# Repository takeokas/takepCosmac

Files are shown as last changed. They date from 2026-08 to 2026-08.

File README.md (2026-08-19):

# takepCosmac
COSMAC CDP1802 Single Board Computer,  1802 MemberChip Card互換

<a href="https://sunrise-ev.com/photos/1802/1802me2-manual.pdf" target=_blank> 1802 MemberChip Card </a> 互換  
<a href="https://hackaday.io/project/190289-1802-memberchip-card" target=_blank> 1802 MemberChip Card in Hackaday.io </a>  

<a href="https://cdn.hackaday.io/files/1902898141324576/MC21ANSA.bin"> MC21ANSA.bin </a> を、ROMの先頭(0番地)から書き込むと動作する  

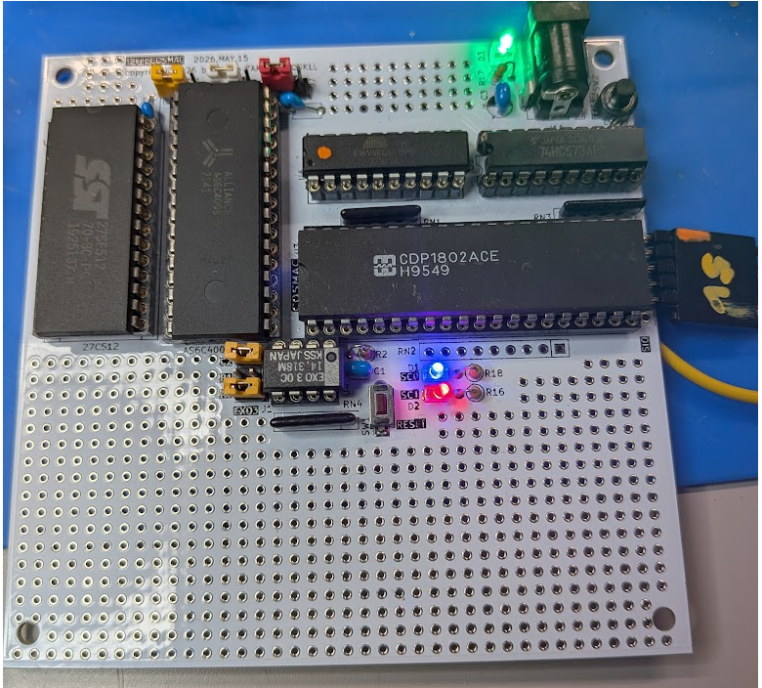
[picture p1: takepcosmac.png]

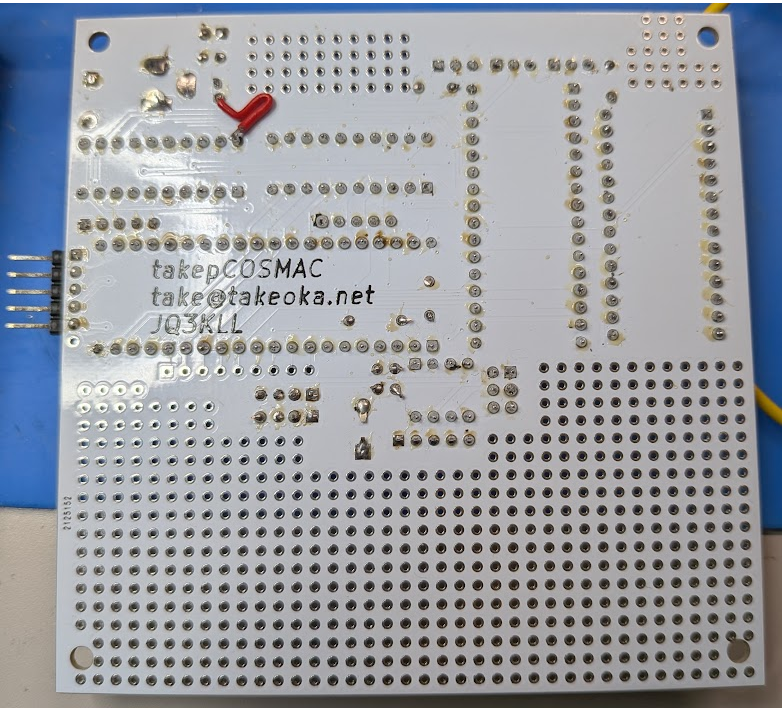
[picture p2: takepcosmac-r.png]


**※74HC573 の電源に +5V を接続すること!!(重要)**  

## Spec  
- RAMは、メモリ空間の後半 32KBytes  
-- S-RAM,  AS6C4008-55PCN (512KW×8bit)1チップ使用  

- ROMは、メモリ空間の前半 32K  
-- EEPROM,  SST 27SF512(64KW×8bit)) 使用  
-- 27C512互換であれば使用可能、2764あたりからそのまま差し込めるはず  
-- ROMの通常アクセスは、前半 32KBytes (0〜0x7FFF)であるが…  
-- ROMの後半 32KBytes (0x8000〜0xFFFF)は、RAMとかぶっているが、IO readアクセスで読み出し可能  
--- ROMの後半を読み出して、RAMに転送することができる!  

- Crystal発振器 EPSON EXO-3, 14.31818 MHz の8分周  
-- CPU は、約 1.7898 MHz で動作  

- GAL16V8 使用  
-- <a href="takepCosmacGal/takepCosmac.pld"> 論理(ソース) </a>  
-- <a href="takepCosmacGal/takepCosmac.jed"> JDECファイル </a>  

- SIO TTLレベル  
-- ソフトウェア実現.4800bps が調子いい  
-- 秋月で販売されている FTDI USBシリアル変換ケーブル(5V) が直接 差せる  
--  https://akizukidenshi.com/catalog/g/g105841/    

## 超簡略 使用方法 説明  
- シリアル・ラインに端末を接続する。ソフトウェアでSIO処理を行っているので、4800bpsが限界ぽい  
- COSMACをリセットする。リセット後、何も出力されない。シリアル端末で「リターン」を押下(\r を送信)
- MC21ANSA が自動で、通信速度を判定。起動メッセージを出力
- 入力する英文字は、大文字のみ  
- 「H」(大文字)で、help が出力される。
- 「P」でアドベンチャーゲーム。詳しくは<a href="https://sunrise-ev.com/photos/1802/1802me2-manual.pdf" target=_blank> 1802 MemberChip Card マニュアルPDF</a> の P.15  
- 「B」で BASIC インタープリタ。  
  -- 起動直後に「Cold start」か尋ねられるので、「C」でコールド・スタート  
  -- 「PR」 で「PRINT」の省略形。他は、一般的な BASIC と同様  
  -- <a href="https://sunrise-ev.com/MembershipCard/BASIC3v11user.pdf"> BASIC のマニュアル </a>  

## 1802 MemberChip Card の特殊なROMチップ・セレクトについて  
- <a href="https://sunrise-ev.com/photos/1802/1802me2-manual.pdf" target=_blank> 1802 MemberChip Card マニュアルPDF</a> の「Banked Memory」の章(P.21)に説明がある  
- <a href="https://hackaday.io/project/190289-1802-memberchip-card" target=_blank> 1802 MemberChip Card in Hackaday.io </a> にも解説がある  

  

- PROMの上位 32KBytes (0x8000〜0xFFFF) を読む方法  
  1.  読み出したいアドレスをレジスタにセットする。ただし、MSBは0にすること。例えば0x9000 を読みたいならば 0x1000 とする  
  2.  Xに、このレジスタの値をセットする。SEX命令などで  
  3.  「INP 0」(オペコード 0x68) 命令を実行する。通常、これは未定義命令である。  
     この命令は、入力ポート(N0-N2線)の指定無しで、読み込みをおこなう  
     CPU は、write サイクルを実行するが、PROMの後半から read し、CPU の Dレジスタに読み込む  
- MC21ANSA モニタの「E」コマンドは、PROMの後半から RAM へのブロック転送を行う  
  - 「E ソース番地 目的番地 バイト数」で、各パラメータは十六進数で指定  
       ソース番地:PROMアドレス、目的番地:RAMアドレス  

### 1802 MemberChip Card の特殊なROMチップ・セレクトの解説  
-- PROMの 下位 32KBを read するとき: A15=0 , /MRD=0 (通常).  
-- しかし、PROMの 下位 32KBに write するとき: A15=0, /MWR=0 , /MRD=1。  
--- /MWR=0 は PROM をチップ・セレクトし、CPUの A15=0 は PROM の read enable し、そして /MRD=1 は ROM address の A15ビットを Hi にする。  
    それにより、PROM の上位(0x8000-0xFFFF)を読み出す。  
--- しかし CPU データ・バスの出力と、PROM の出力がぶつかるのは困る。よって、CPUの INP 命令を使用する。(INP命令はデータ・バスに何も出さない)      
--- 以上により、CPU の Dレジスタに PROM のデータが入る

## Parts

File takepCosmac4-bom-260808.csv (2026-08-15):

# | Reference | Qty | Value | Footprint | DNP
1 | C1 | 1 | 10uF | Capacitor_THT:C_Disc_D3.0mm_W2.0mm_P2.50mm
2 | C2, C4, C5 | 3 | 0.1uF | Capacitor_THT:C_Disc_D4.7mm_W2.5mm_P5.00mm
3 | C3 | 1 | 電解10uF | Capacitor_THT:CP_Radial_D4.0mm_P2.00mm
4 | D1, D2 | 2 | LED | LED_THT:LED_D1.8mm_W3.3mm_H2.4mm
5 | D3 | 1 | LED | LED_THT:LED_D3.0mm
6 | H1, H2, H3, H4 | 4 | MountingHole | MountingHole:MountingHole_3.2mm_M3
7 | J1 | 1 | HEADER_3x2 | Connector_PinHeader_2.54mm:PinHeader_2x03_P2.54mm_Vertical
8 | J3 | 1 | HEADER_3,RAM0a18 | Connector_PinHeader_2.54mm:PinHeader_1x03_P2.54mm_Vertical
9 | J5 | 1 | HEADER_6,SIOA | Connector_PinHeader_2.54mm:PinHeader_1x06_P2.54mm_Horizontal
10 | J6 | 1 | HEADER_3,RAM0a17 | Connector_PinHeader_2.54mm:PinHeader_1x03_P2.54mm_Vertical
11 | J7 | 1 | HEADER_3,RAM0a16 | Connector_PinHeader_2.54mm:PinHeader_1x03_P2.54mm_Vertical
12 | J11 | 1 | Barrel_Jack | Connector_BarrelJack:BarrelJack_GCT_DCJ200-10-A_Horizontal
13 | R1 | 1 | 10K | Resistor_THT:R_Axial_DIN0207_L6.3mm_D2.5mm_P7.62mm_Horizontal
14 | R2 | 1 | 10K | Resistor_THT:R_Axial_DIN0207_L6.3mm_D2.5mm_P2.54mm_Vertical
15 | R16, R18 | 2 | R,330 | Resistor_THT:R_Axial_DIN0207_L6.3mm_D2.5mm_P2.54mm_Vertical
16 | R17 | 1 | 330 | Resistor_THT:R_Axial_DIN0207_L6.3mm_D2.5mm_P2.54mm_Vertical
17 | RN1, RN4 | 2 | R_Network04,10K | Resistor_THT:R_Array_SIP5
18 | RN2 | 1 | R_Network_22K | Resistor_THT:R_Array_SIP9
19 | RN3 | 1 | R_Network04.10K | Resistor_THT:R_Array_SIP5
20 | SW1 | 1 | Reset | Button_Switch_THT:SW_PUSH_1P1T_6x3.5mm_H5.0_APEM_MJTP1250
21 | SW2 | 1 | EF4 | Button_Switch_THT:SW_PUSH_1P1T_6x3.5mm_H5.0_APEM_MJTP1250
22 | U1 | 1 | AS6C4008-55PCN | Package_DIP:DIP-32_W15.24mm
23 | U3 | 1 | CDP1802ACE | Package_DIP:DIP-40_W15.24mm_Socket
24 | U4 | 1 | EXO3 クリスタルオシレータ 14.31818MHz | Package_DIP:DIP-8_W7.62mm |  | https://akizukidenshi.com/catalog/g/g101685/
25 | U5 | 1 | 74LS573 | Package_DIP:DIP-20_W7.62mm
26 | U6 | 1 | GAL16V8D-10QPN | Package_DIP:DIP-20_W7.62mm_Socket
27 | U8 | 1 | 27C512 | Package_DIP:DIP-28_W15.24mm_Socket

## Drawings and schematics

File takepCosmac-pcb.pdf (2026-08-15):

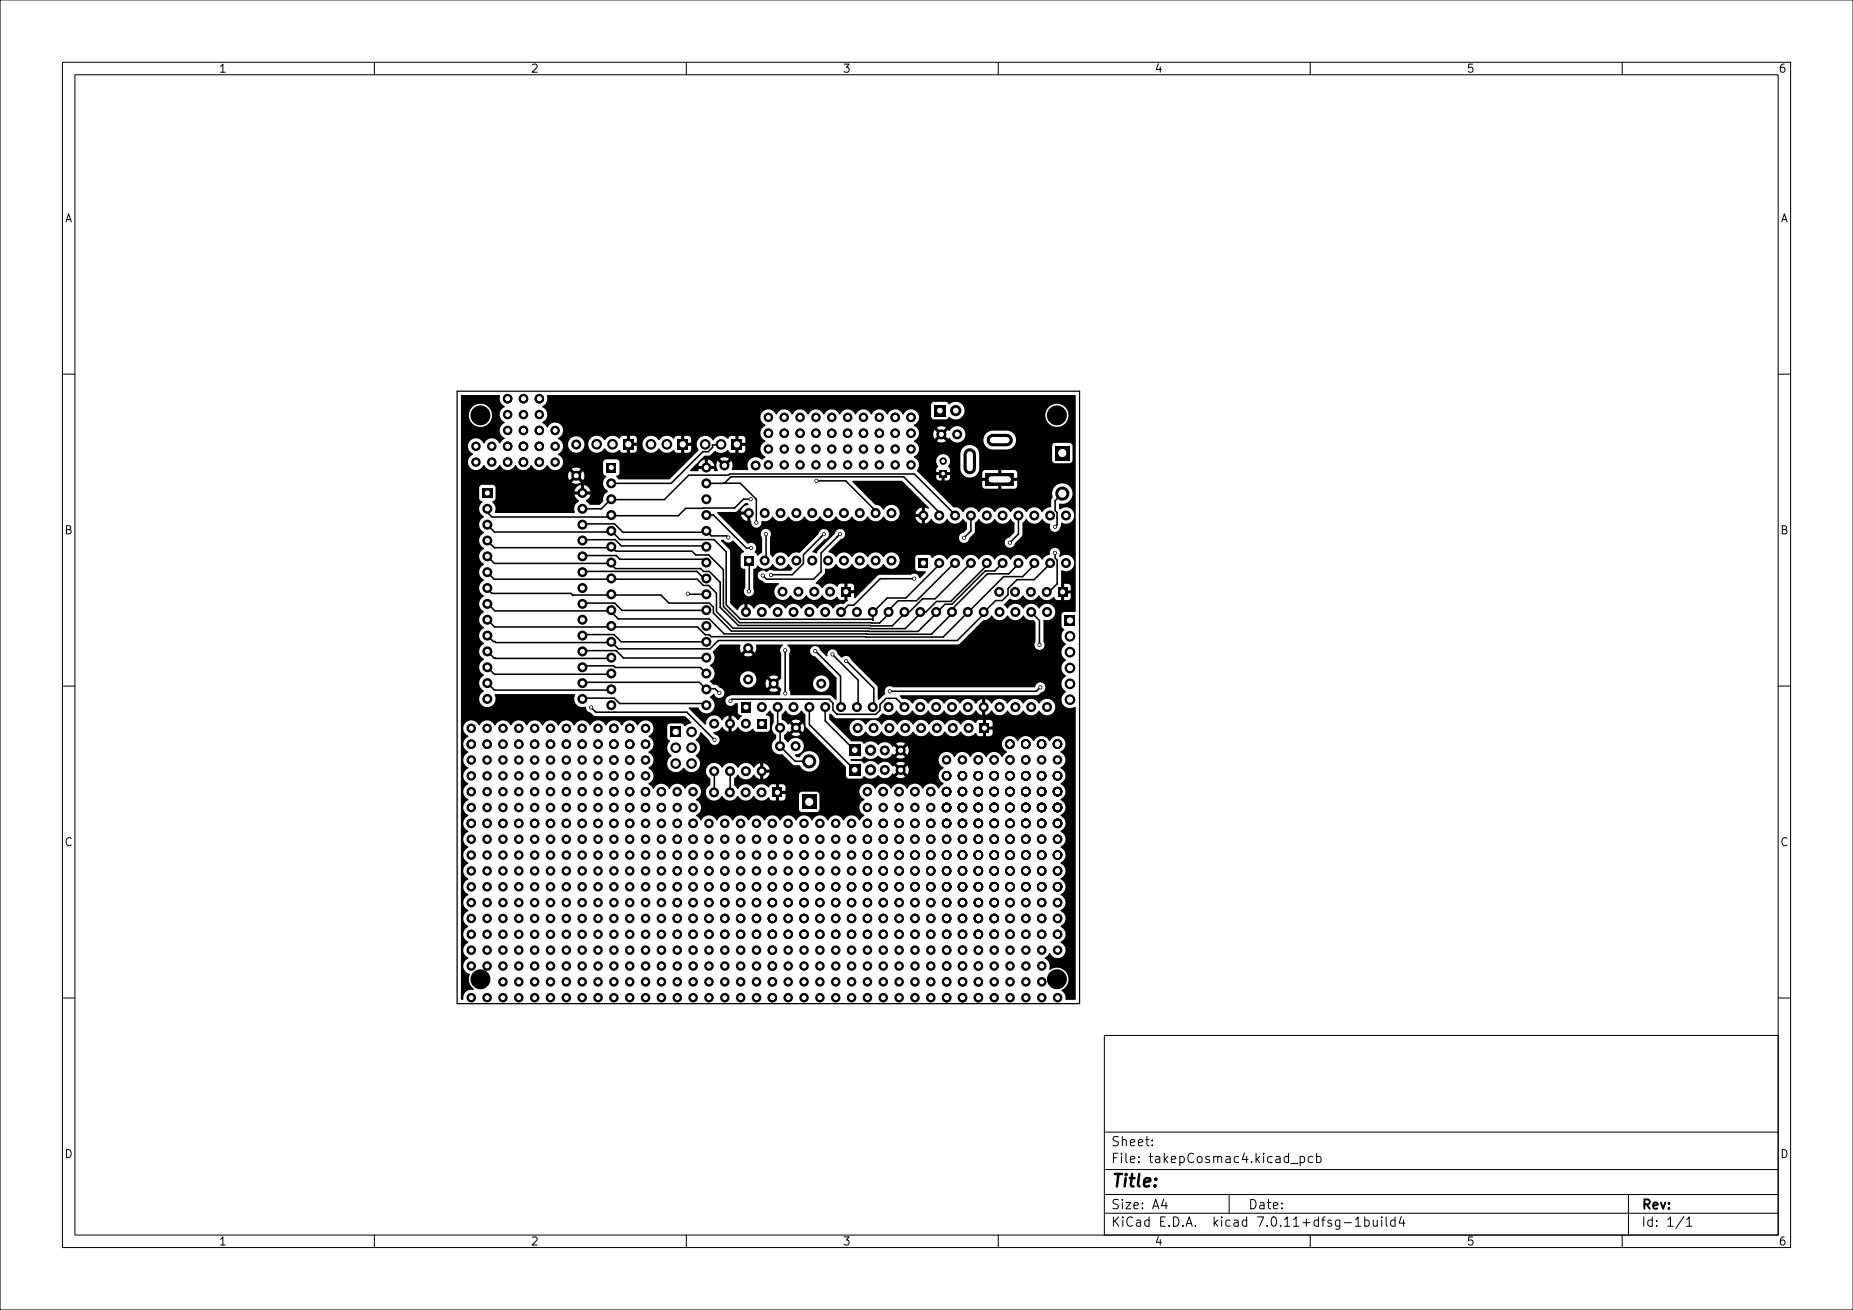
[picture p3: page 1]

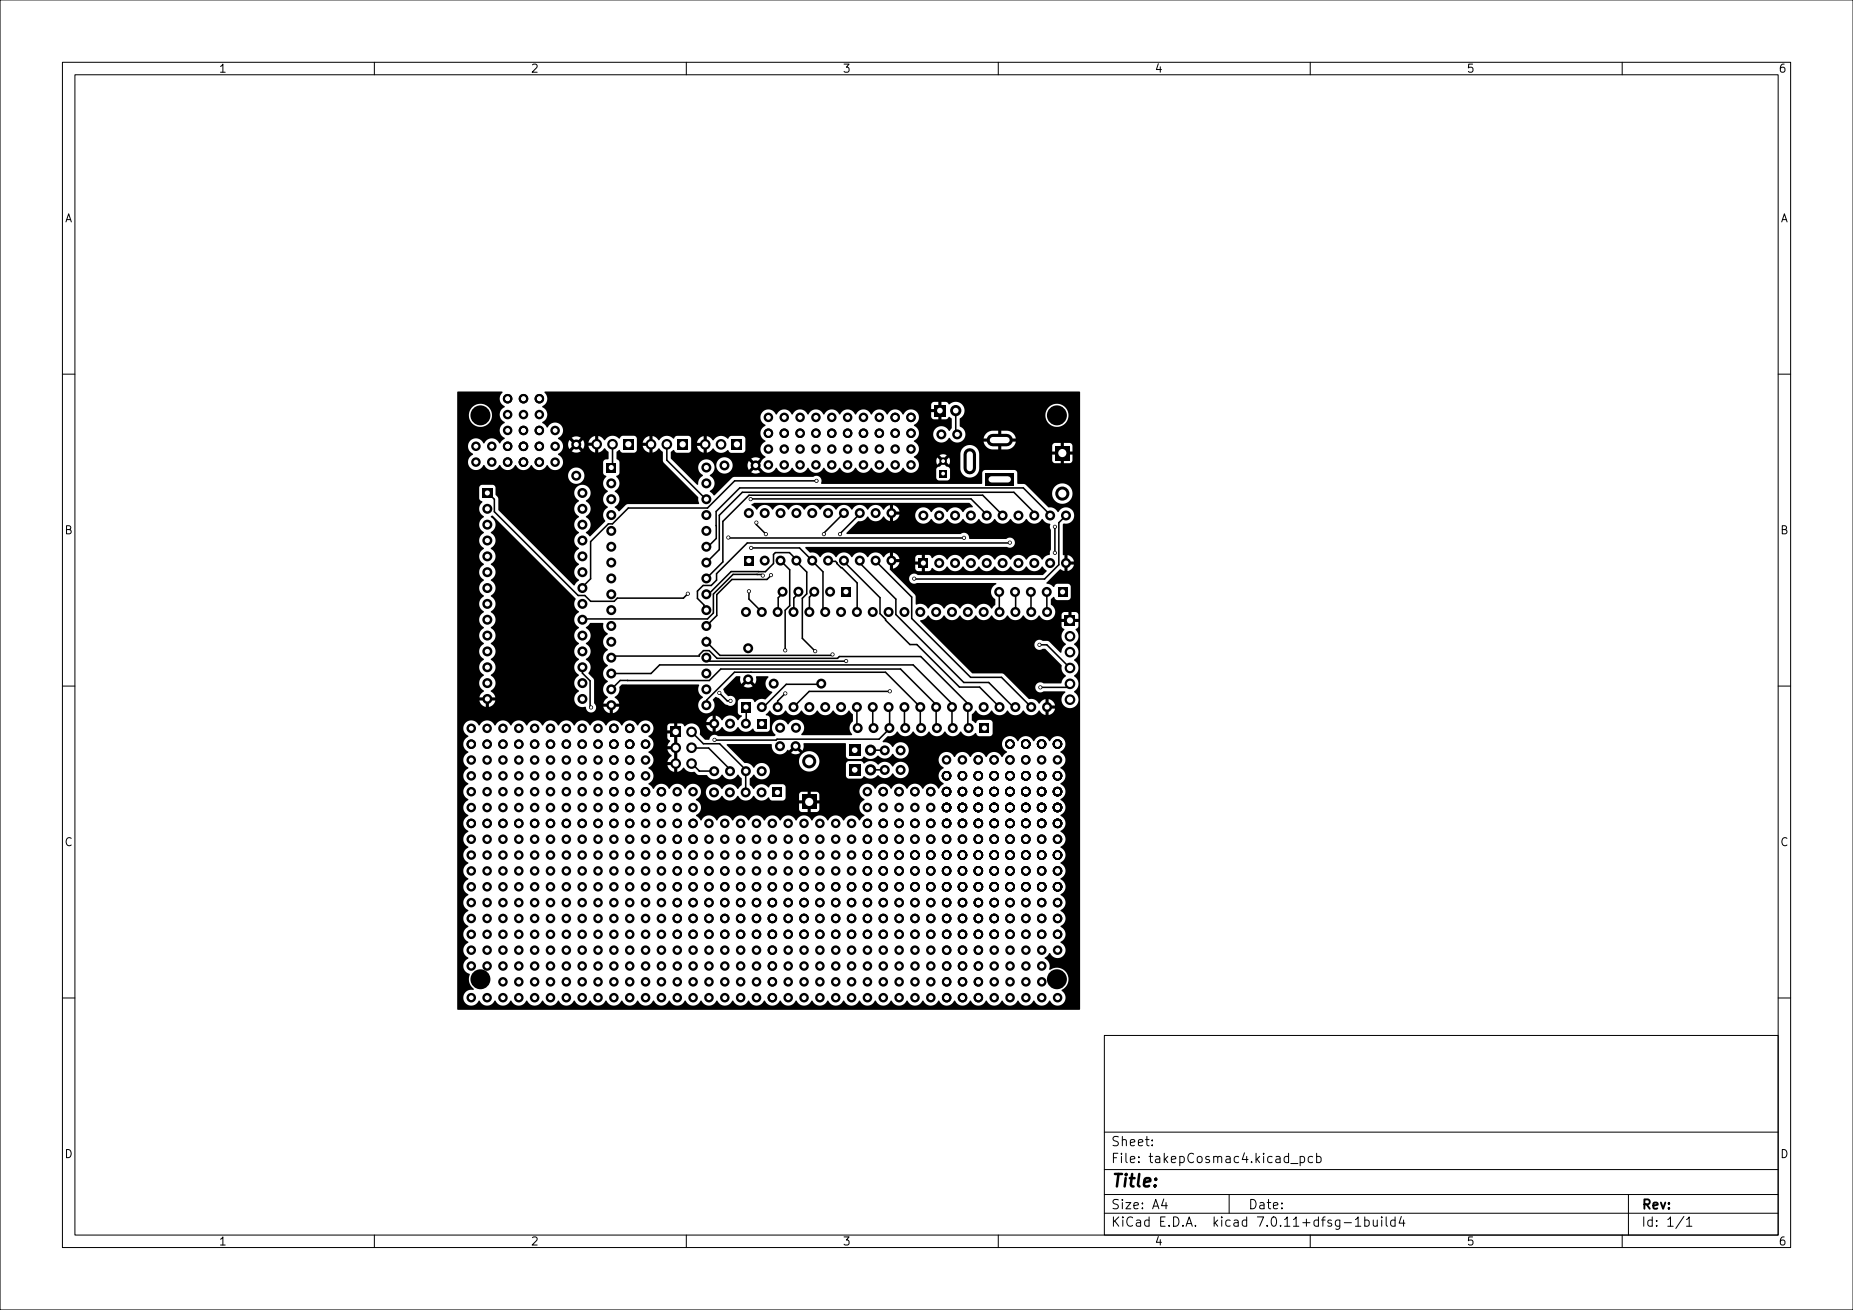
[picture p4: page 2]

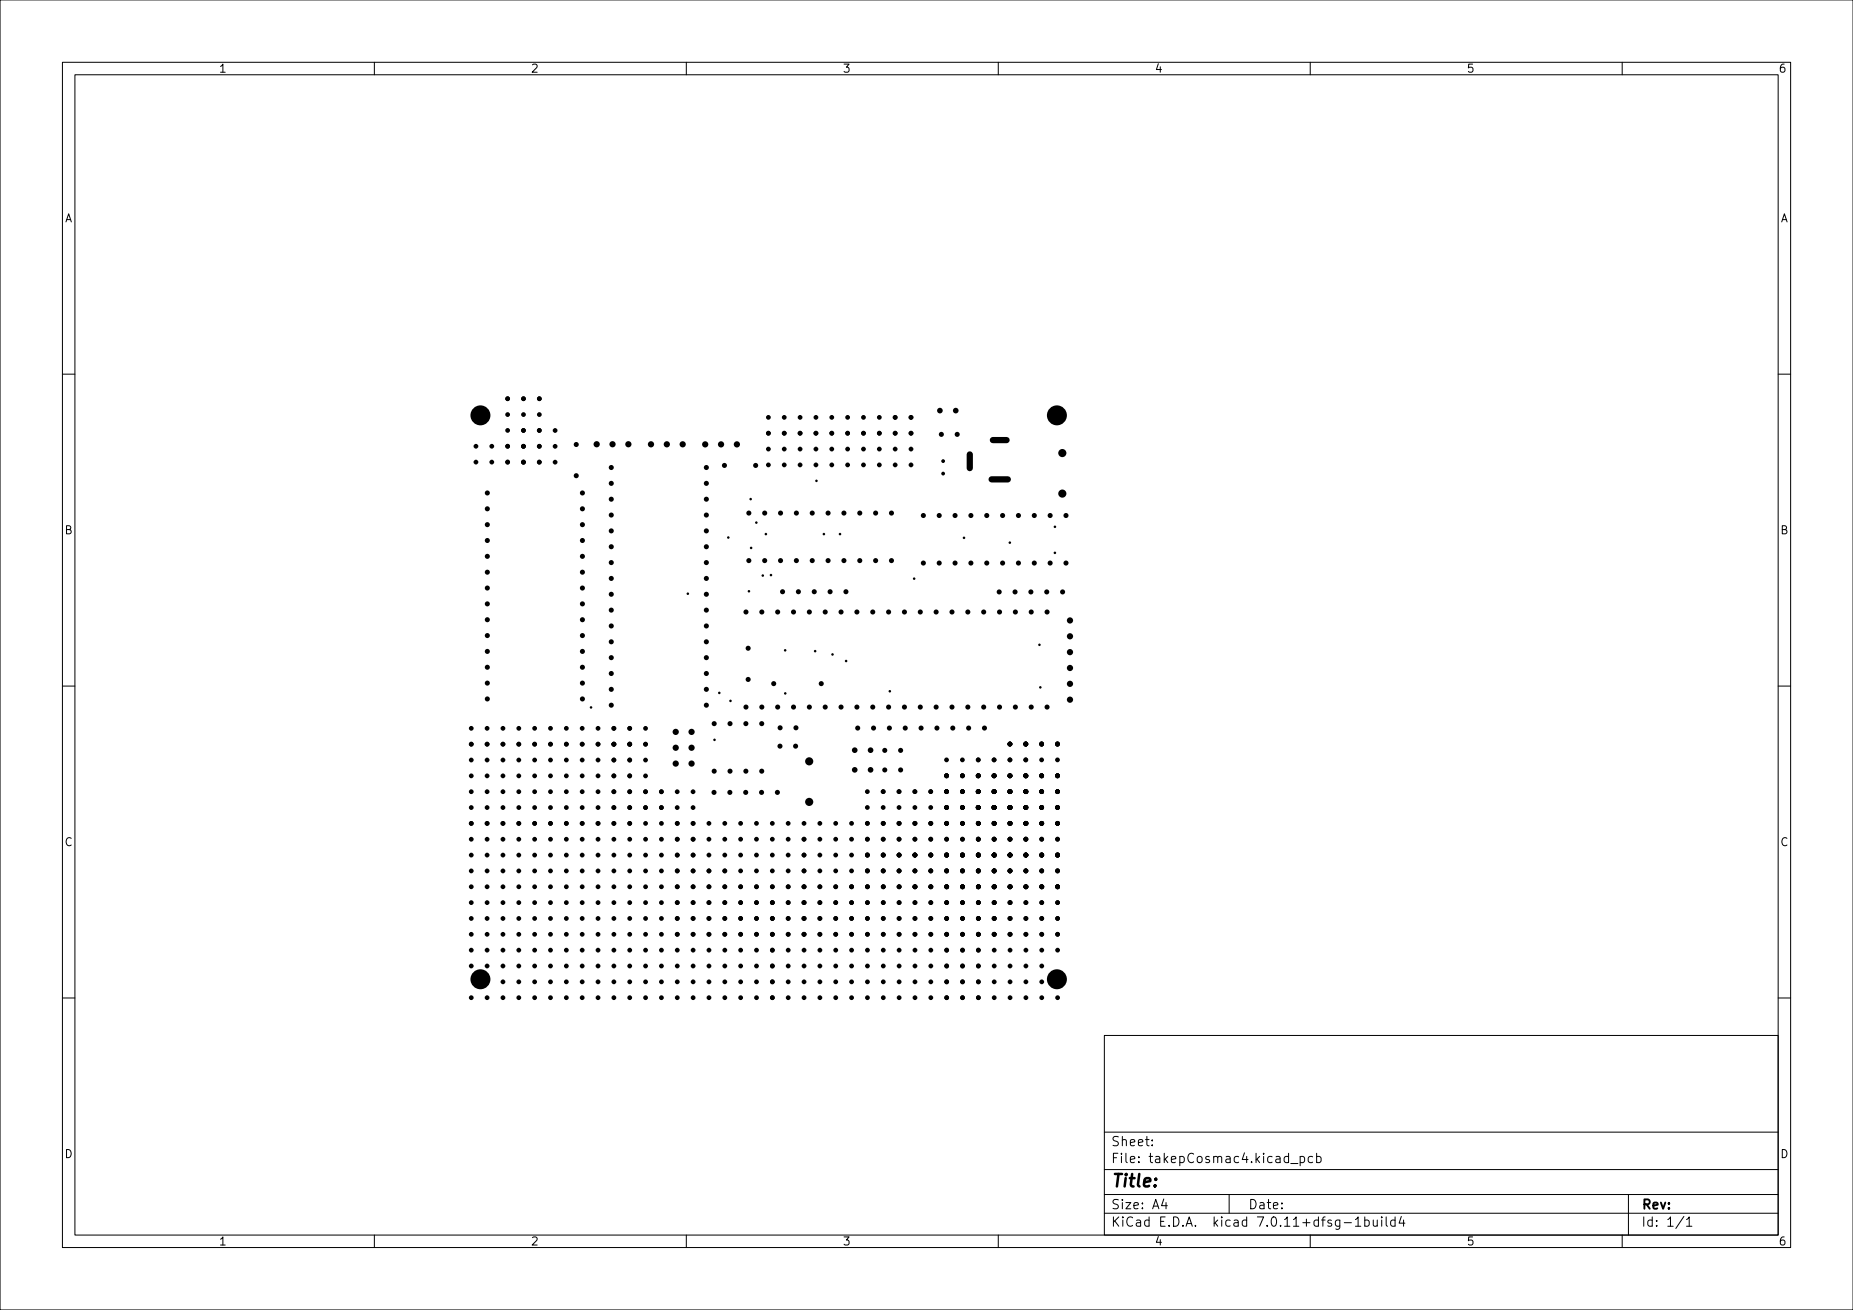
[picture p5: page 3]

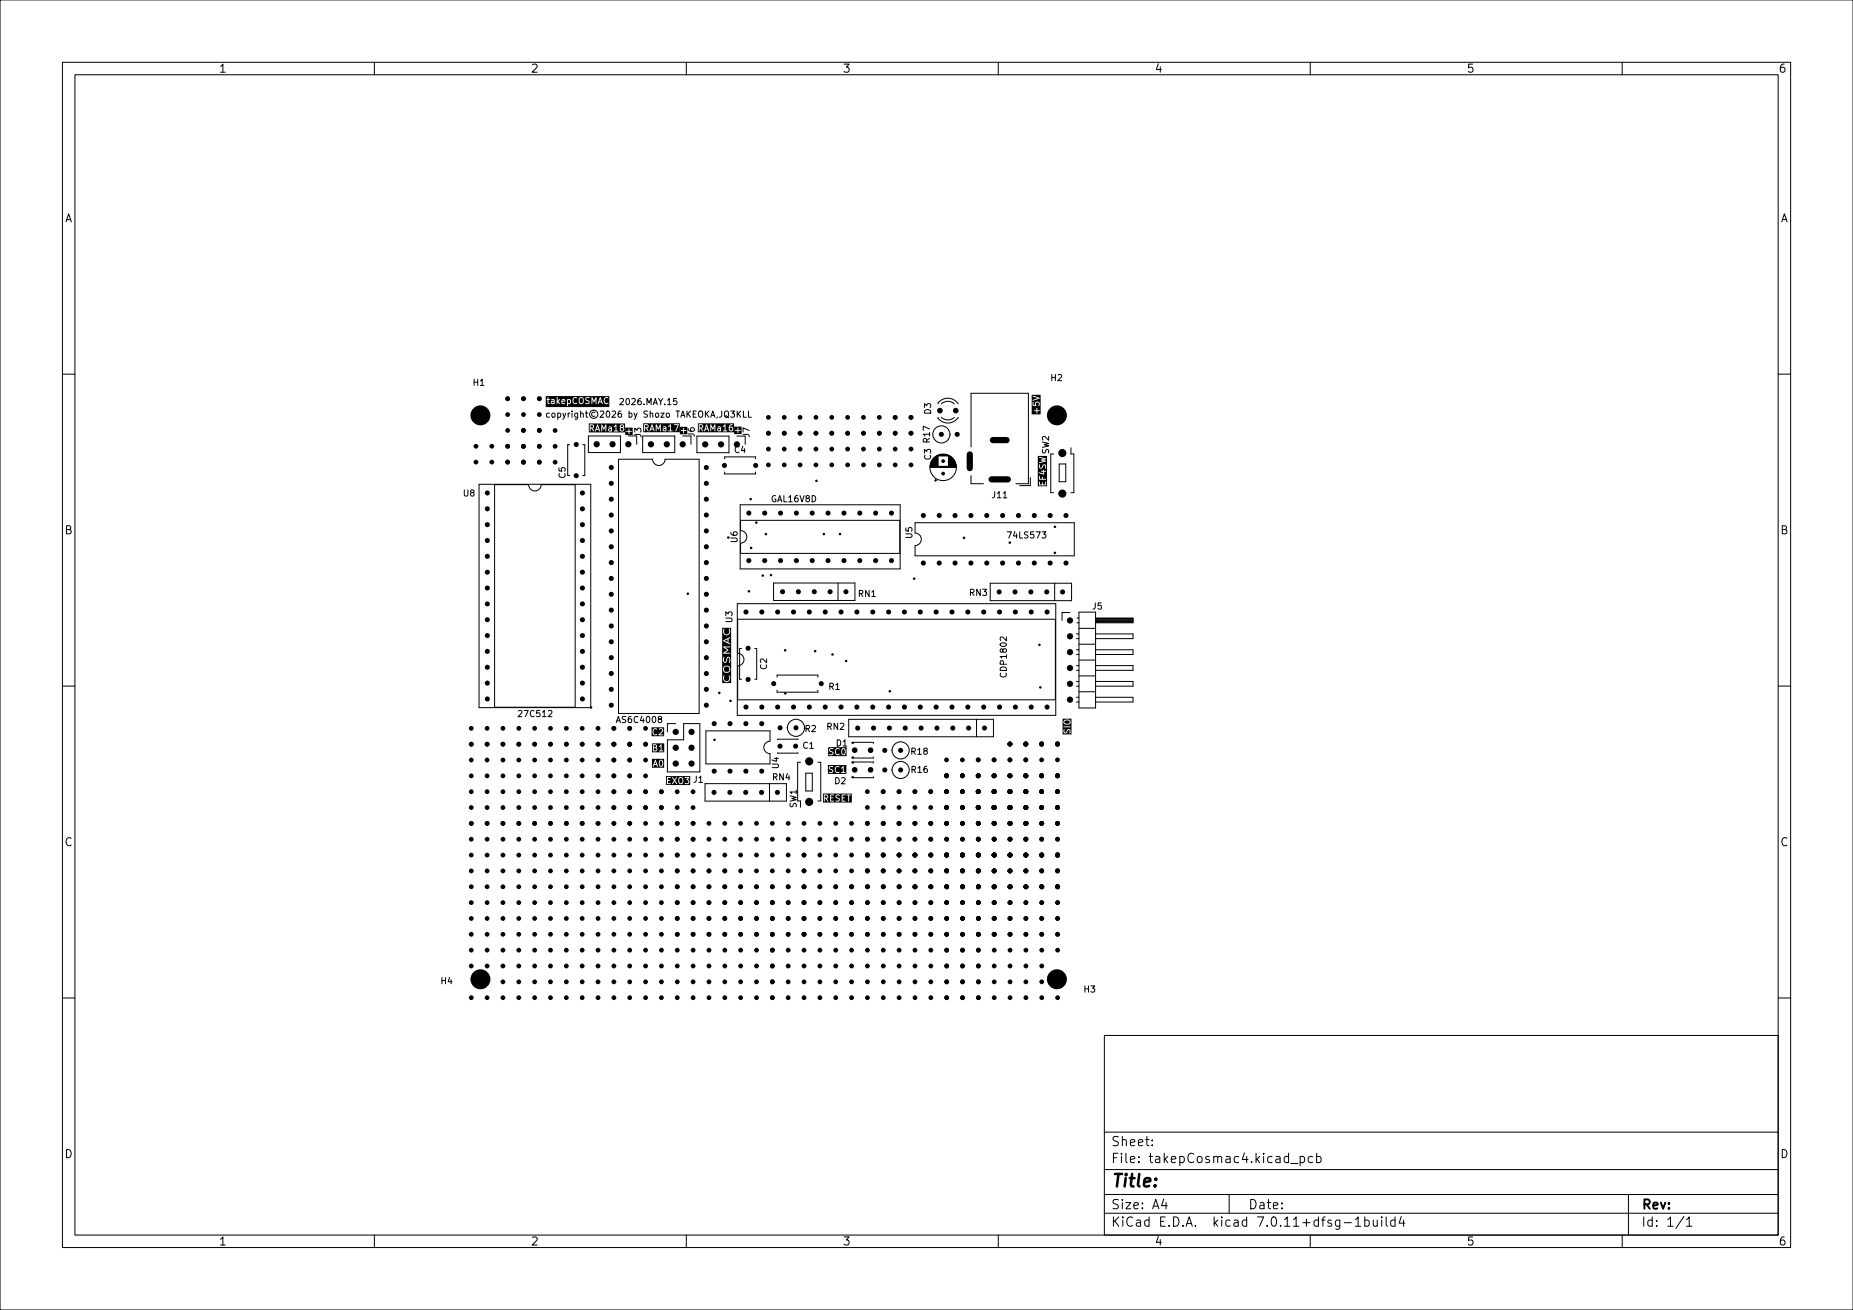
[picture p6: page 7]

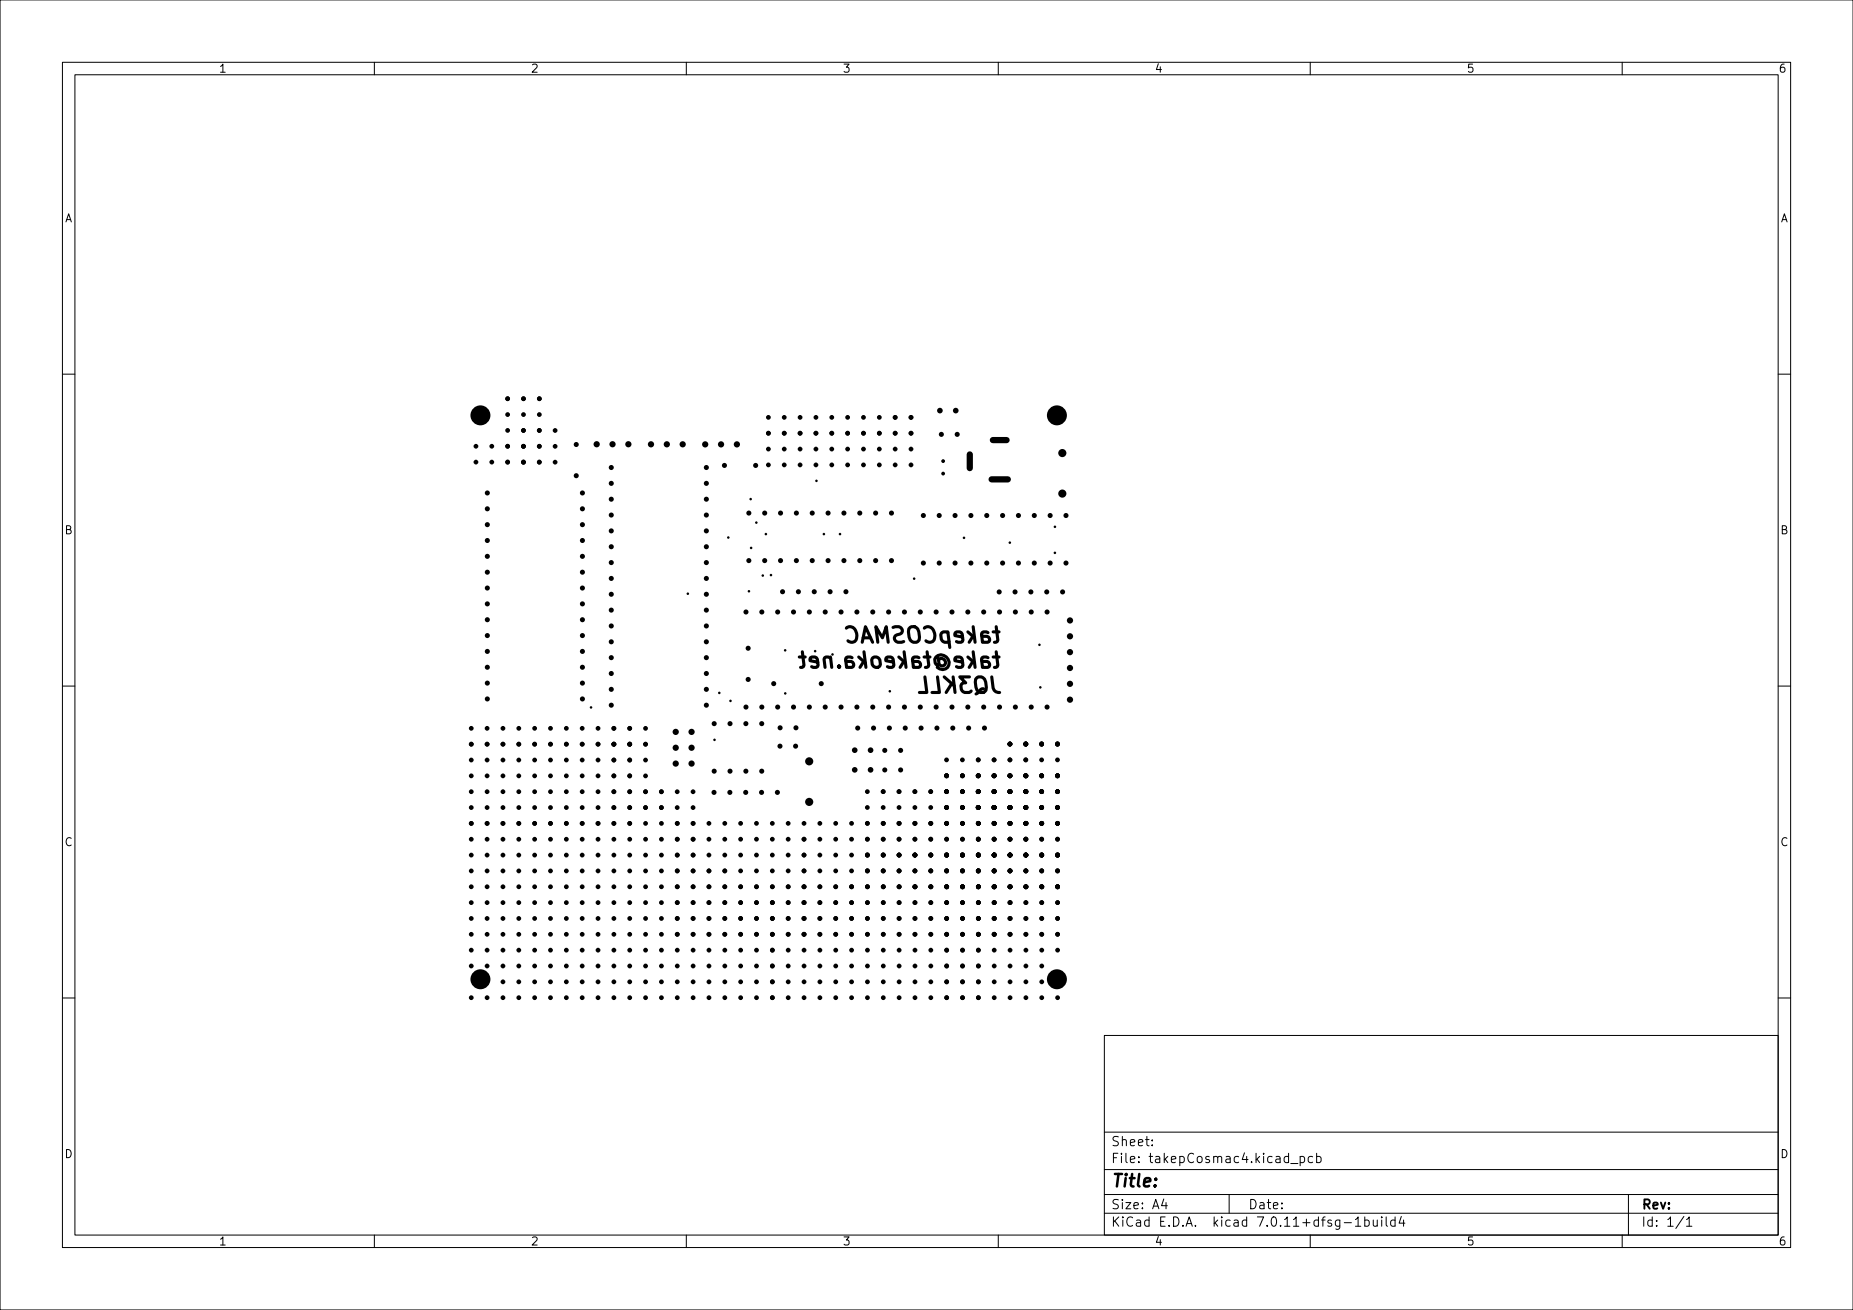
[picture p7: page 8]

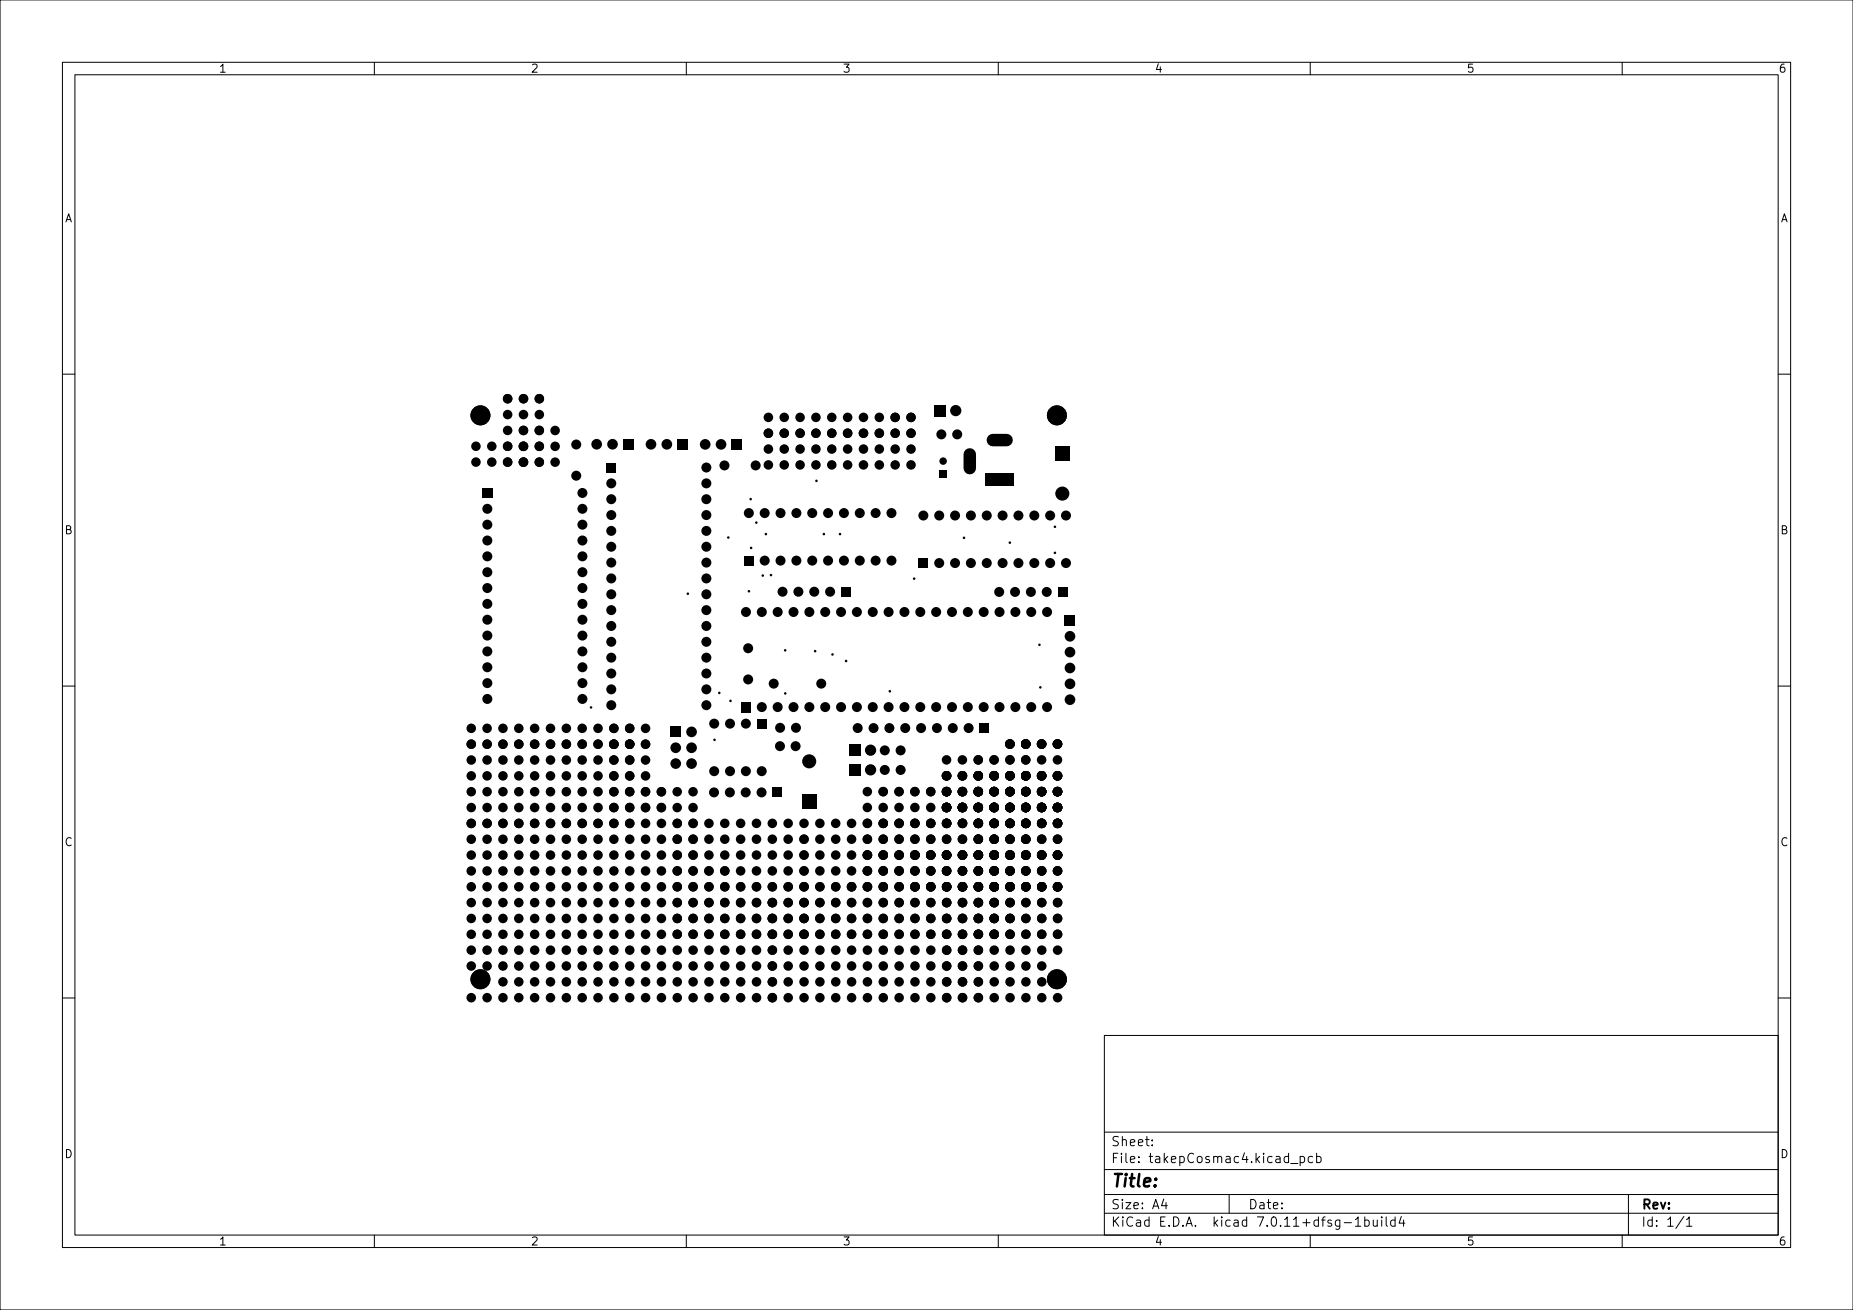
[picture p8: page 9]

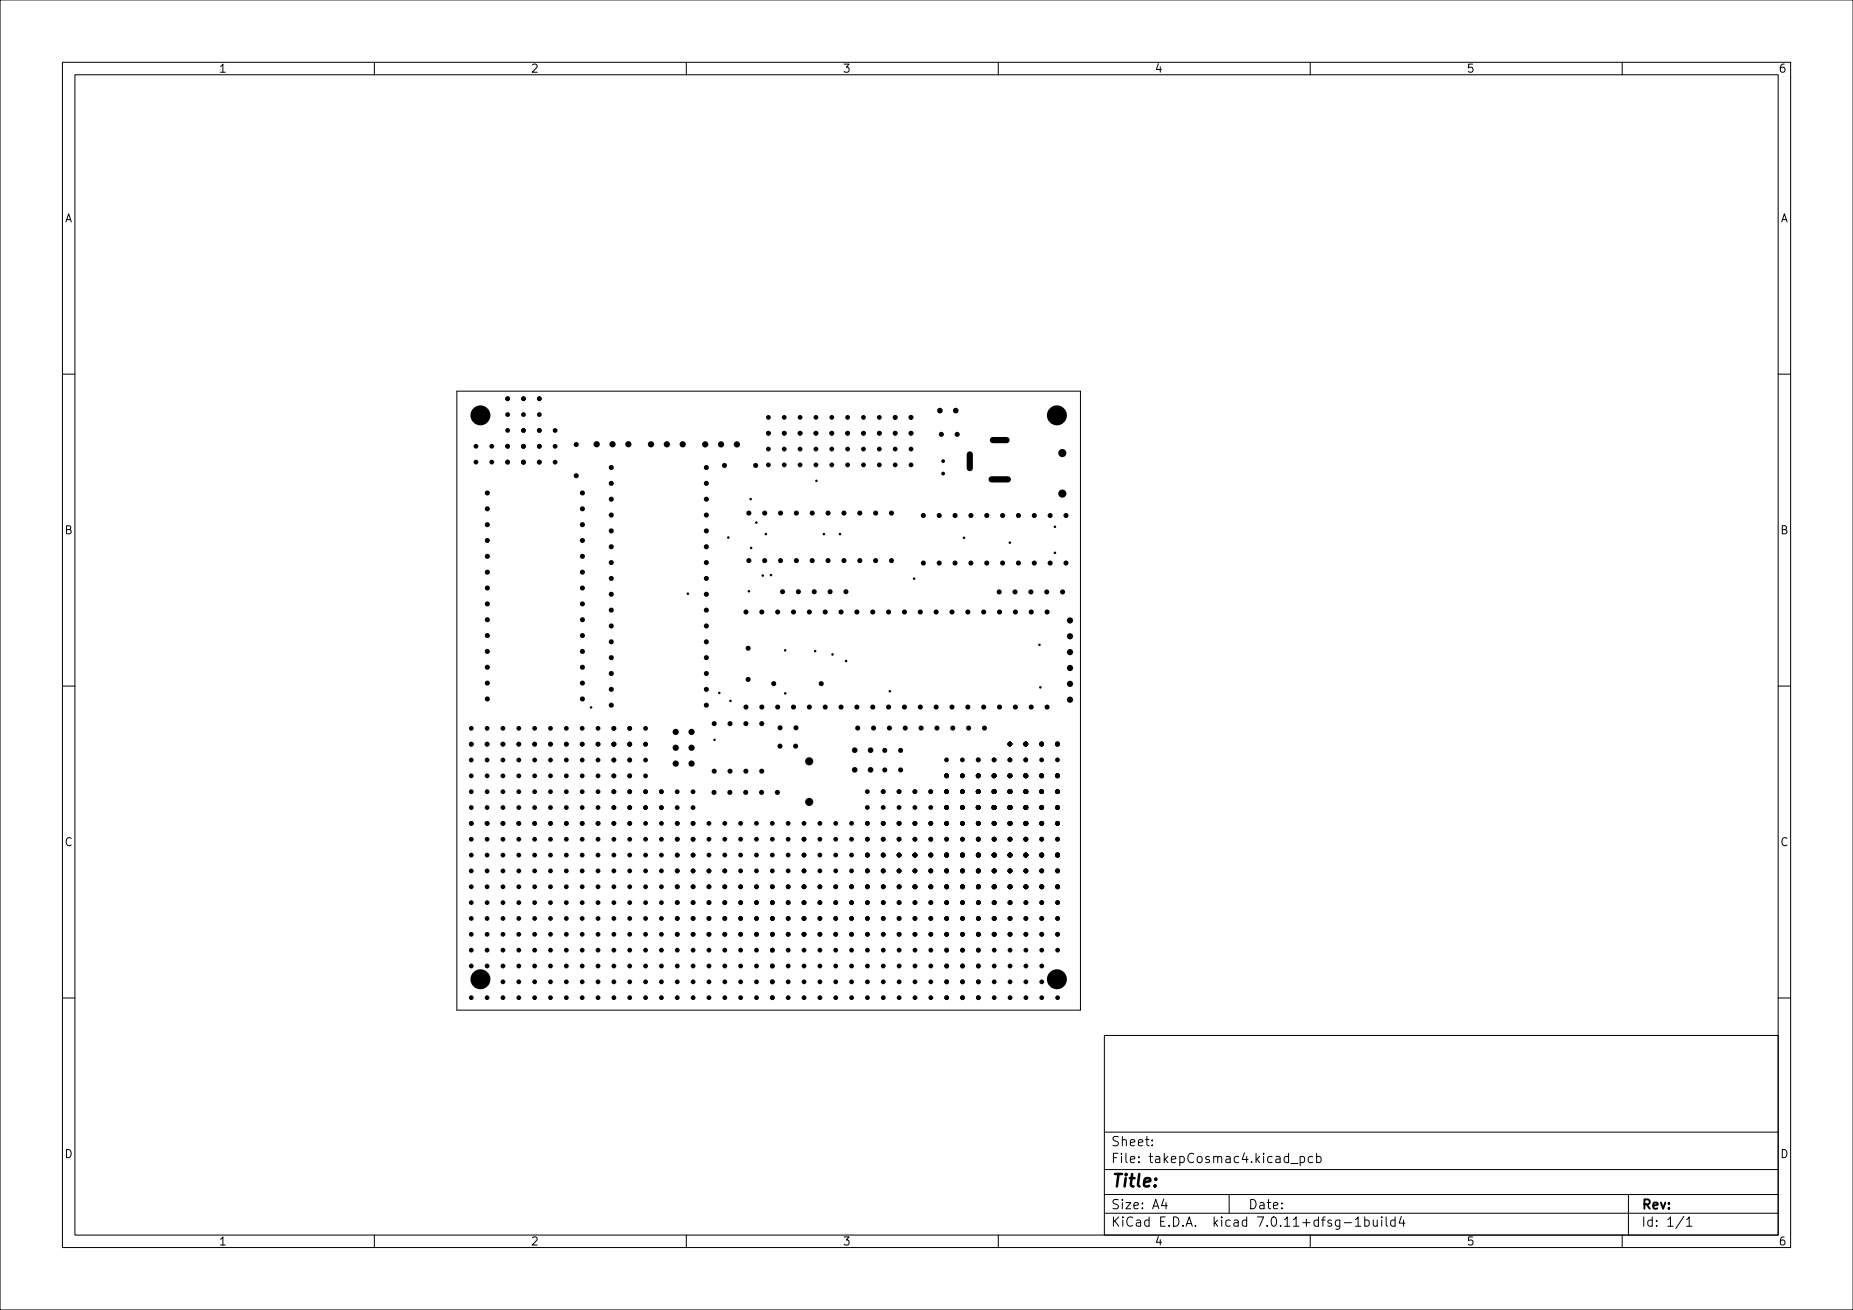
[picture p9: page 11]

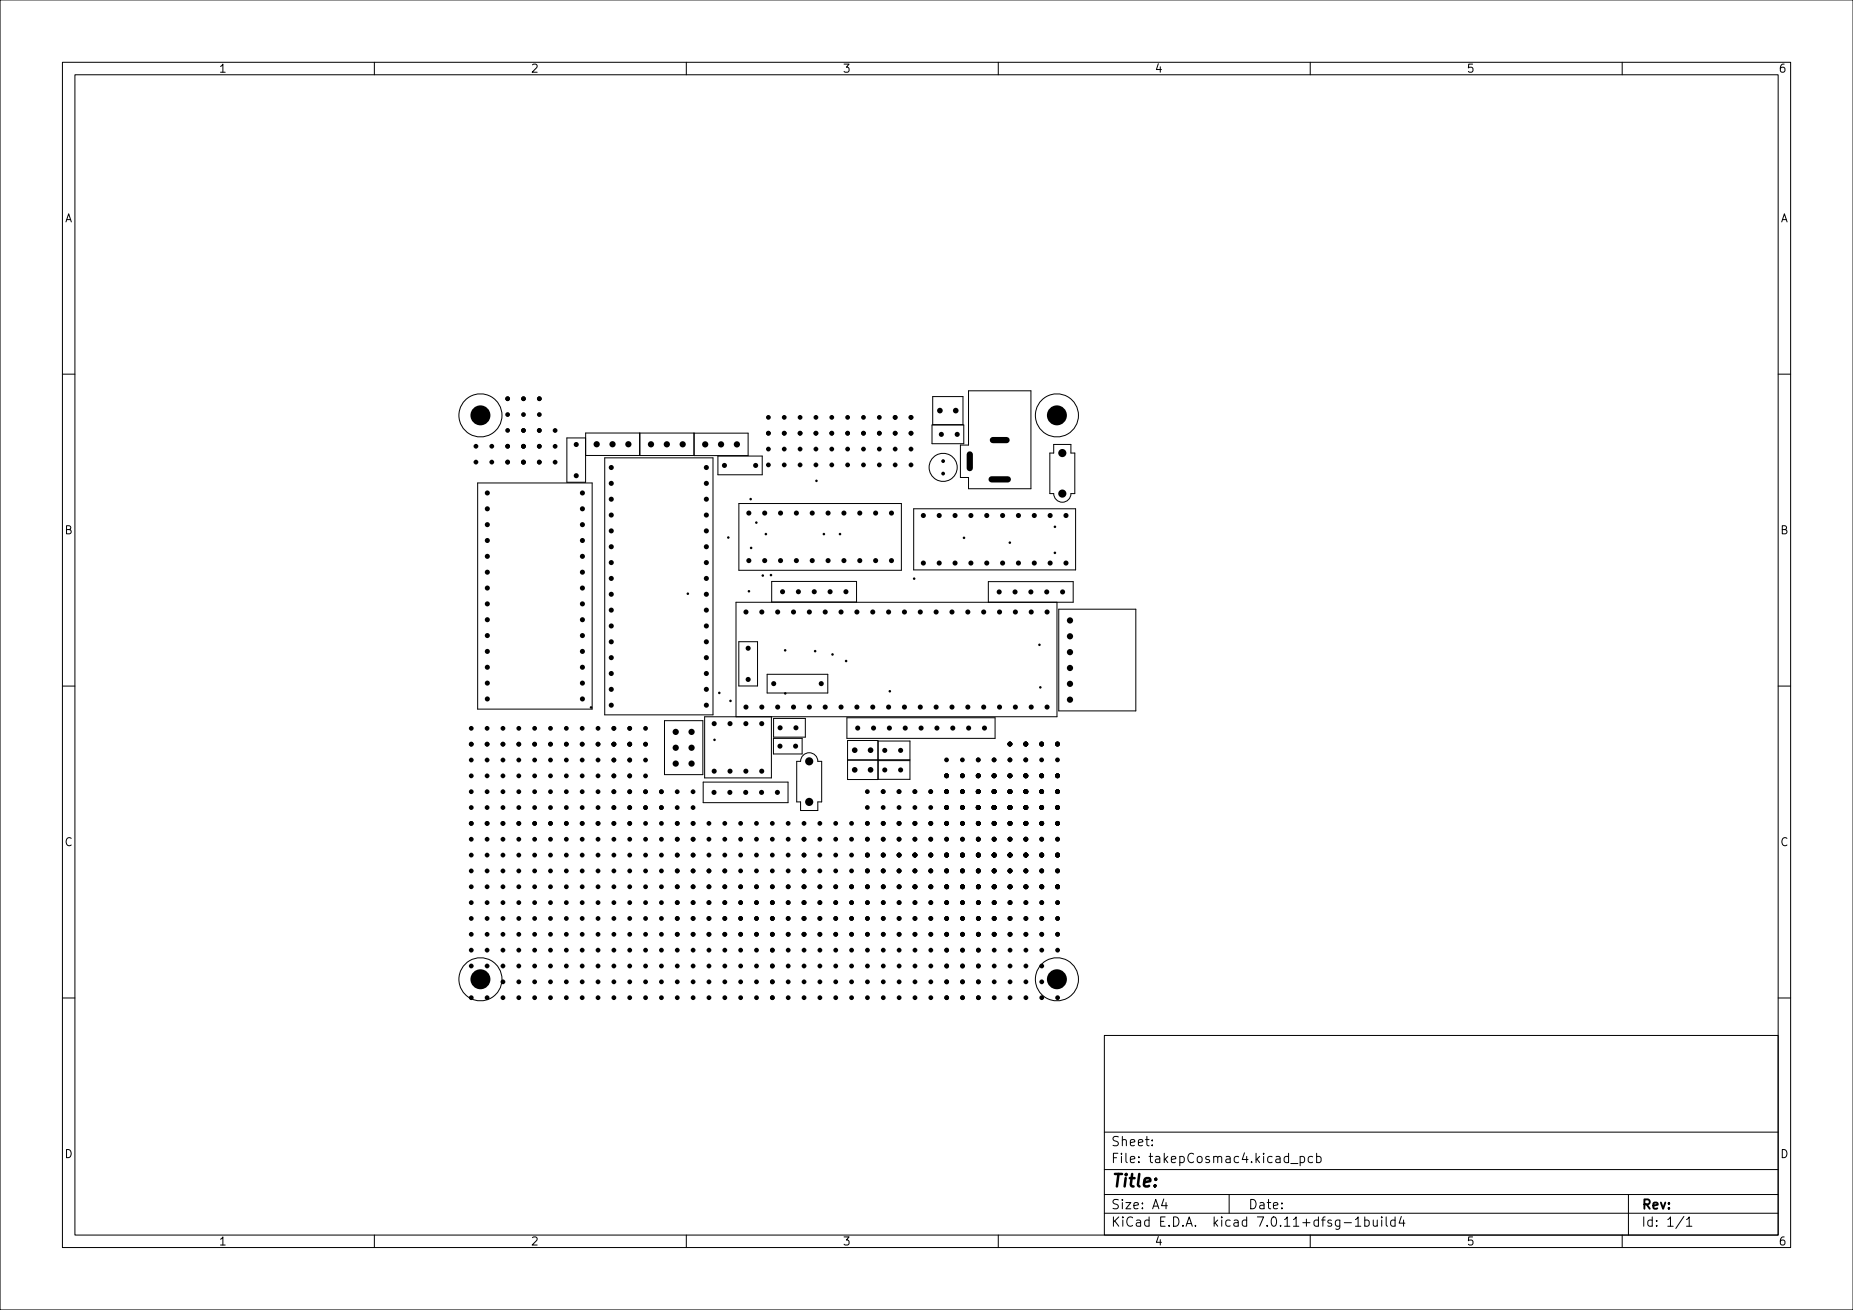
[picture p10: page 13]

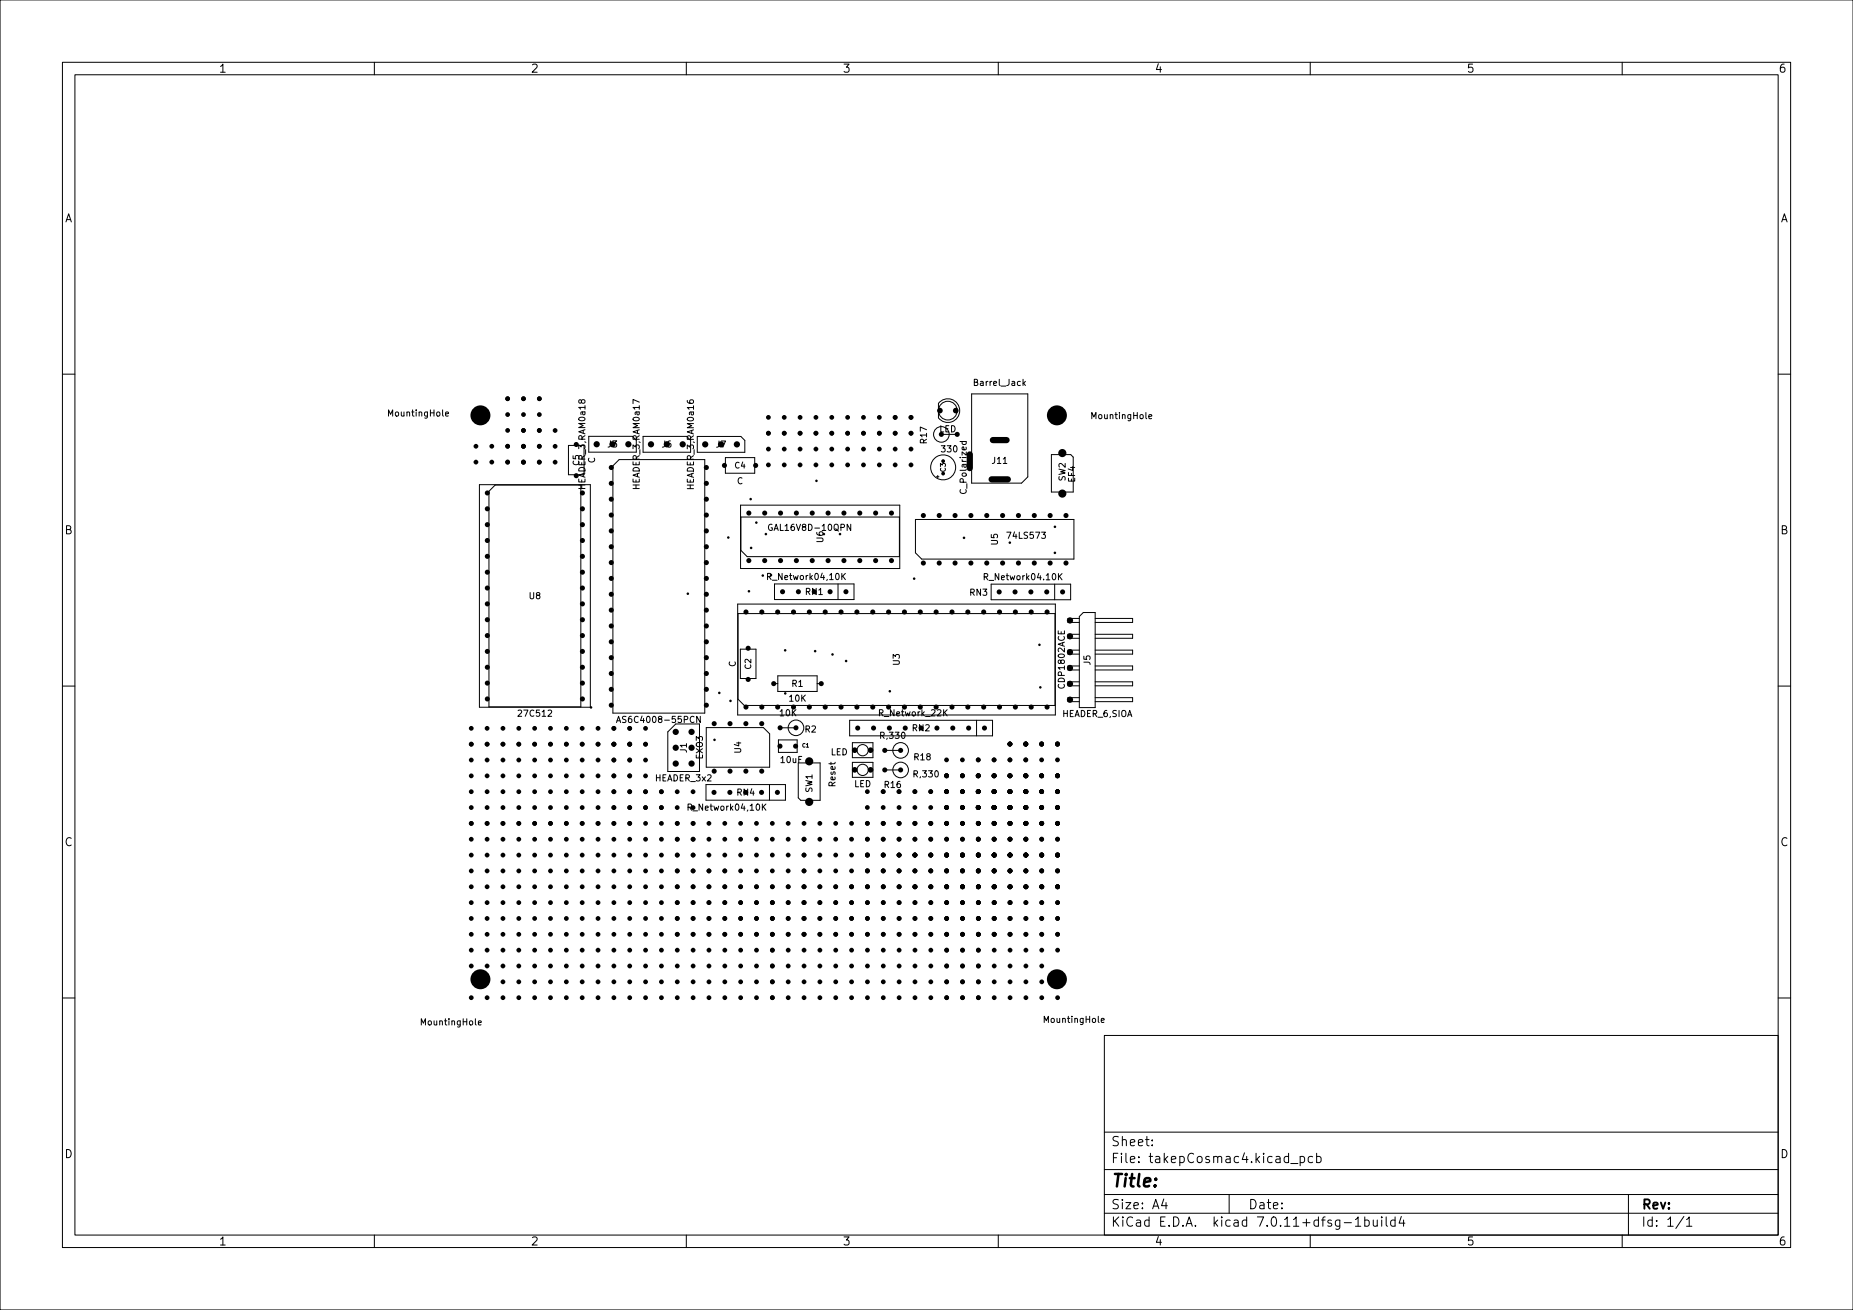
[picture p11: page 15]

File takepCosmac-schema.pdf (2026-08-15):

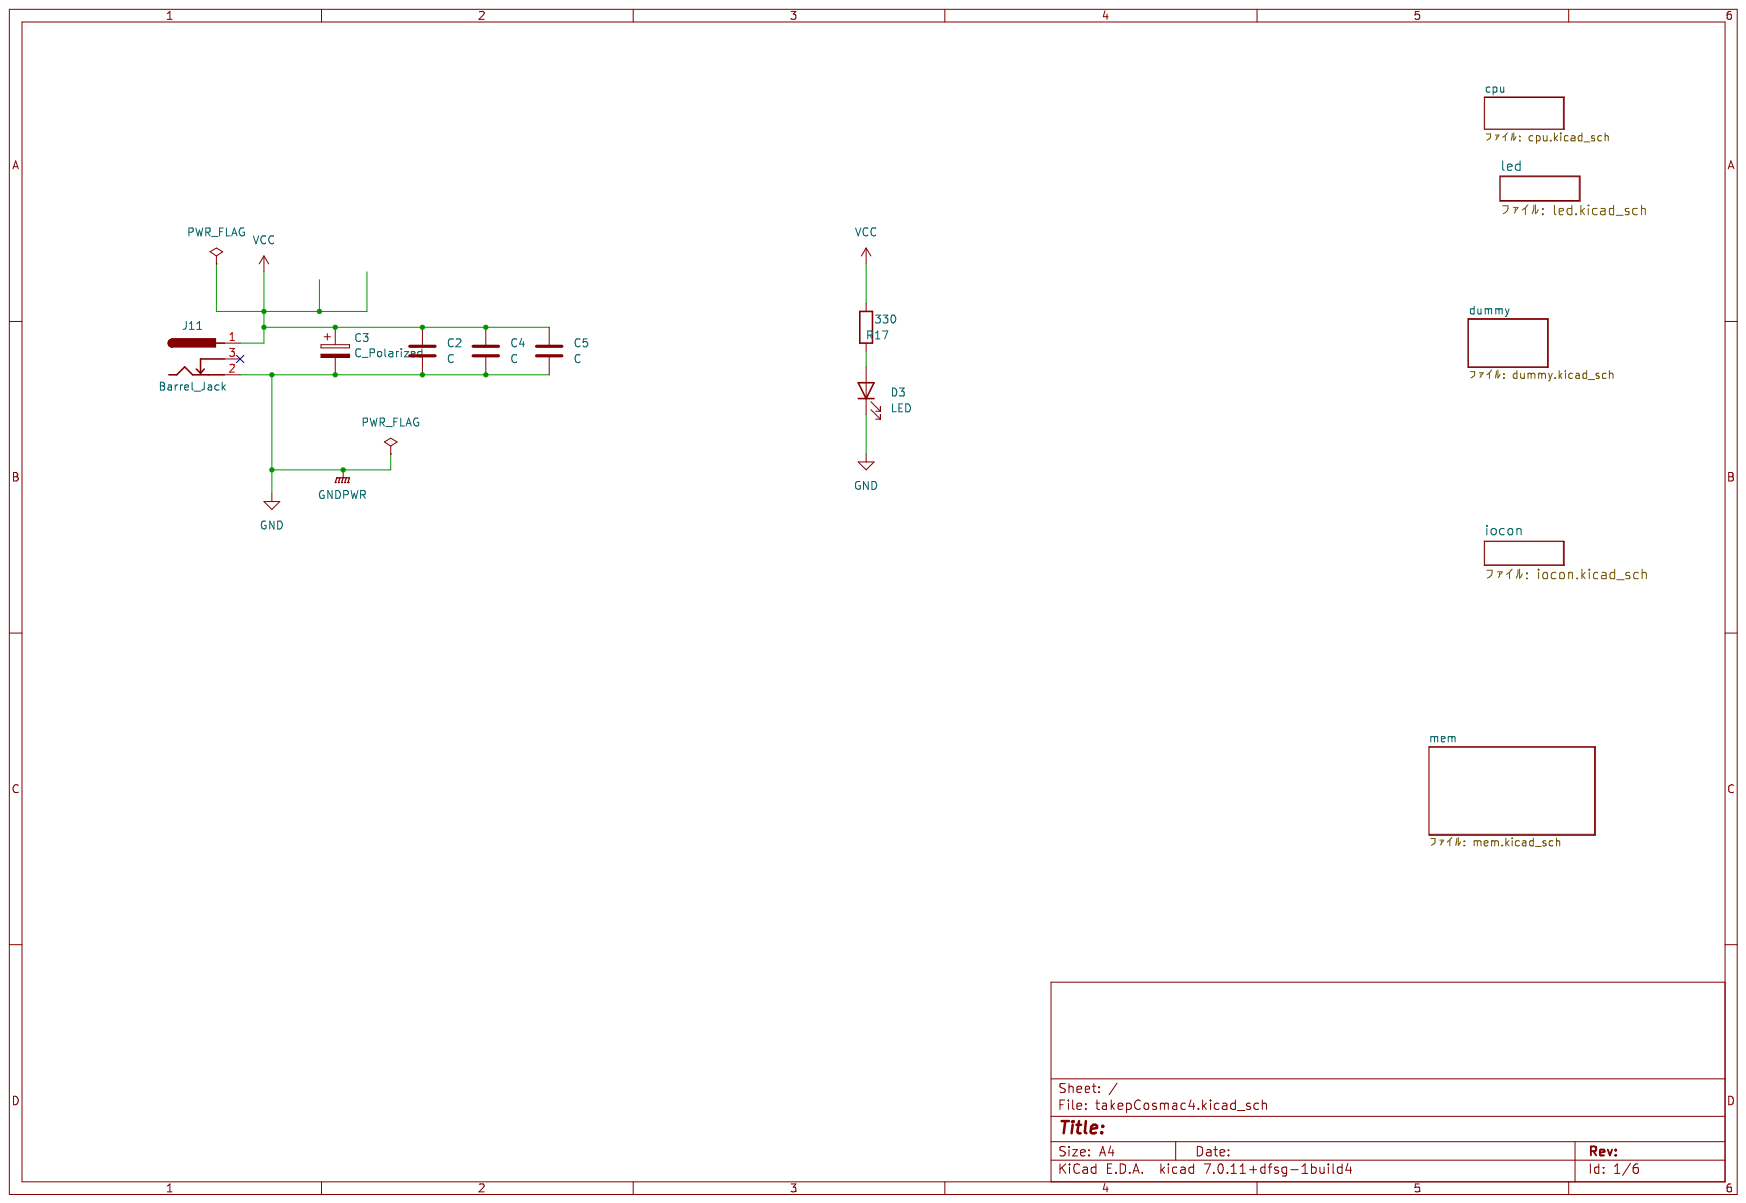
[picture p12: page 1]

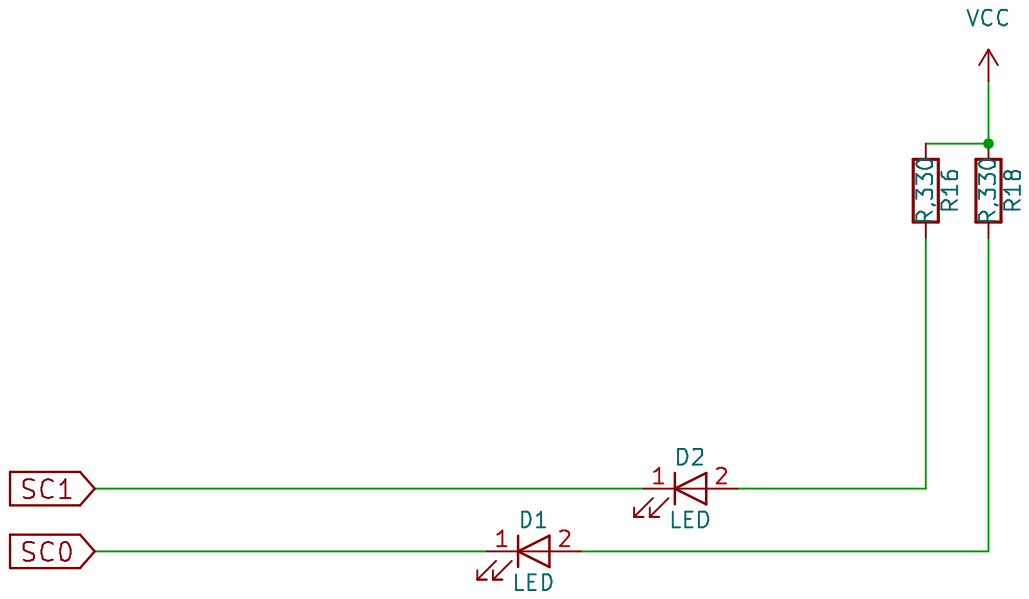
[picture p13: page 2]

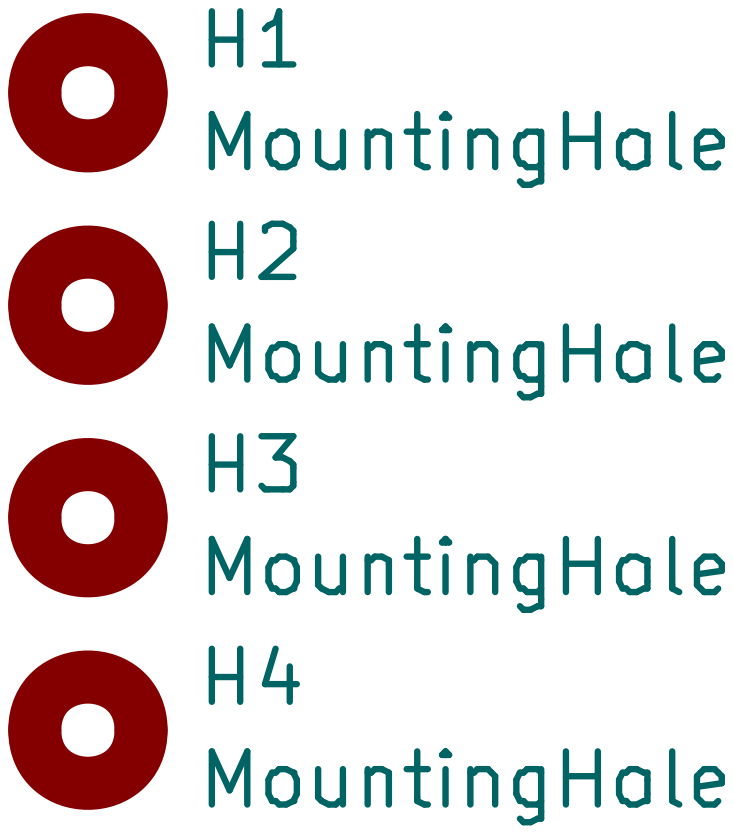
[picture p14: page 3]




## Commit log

2026-08-15 Update README to remove board and circuit sections
    Removed sections about the board and circuit from the README.
2026-08-15 Add important note for 74HC573 power supply
    Added a note about connecting +5V to the 74HC573 power supply.
